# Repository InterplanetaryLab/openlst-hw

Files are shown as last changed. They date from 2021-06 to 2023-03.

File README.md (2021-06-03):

Interplanetary Initiative Lab Fork - OpenLST Reference Hardware
==========================
Due to the Qorvo Power Amplifier in the original design being deprecated, 
the power amplifier was swapped to the newer Qorovo RFFM6406. 
This was more of just a name change as the pinout is identical and the 
electrical specifications of both chips are nearly identical.

*Note - Gerbel files should not need to be updated *

OpenLST Reference Hardware
==========================

This repository contains a KiCad project with a hardware reference
implementation for the OpenLST.  This design is a simplified version
of the Texas Instruments CC1110 432 MHz reference design.  A 1 watt
power amplifier module has been added to increase operating range.
The design is intended for use at 437 MHz, however, it may be modified
for use at other frequencies.

The user is responsible for obtaining and maintaining the necessary
license to operate this radio.  The example project uses frequencies
in the US Amateur Radio UHF band. Transmissions in this band require a
valid FCC license and compliance with CFR Part 97.

board rendering

Contents
--------

This repository contains the following items:

  * [KiCAD 4.0](http://kicad-pcb.org/) project with self-contained part library
  * [Schematic](pdf/openlst-hw.pdf) in PDF form
  * [Bill of materials](bom/) with ordering information for components
  * [Gerber files](gerber/) for PCB fabrication

License & Legal Information
---------------------------

Copyright 2018 Planet Labs Inc. This work is licensed under a
Creative Commons Attribution-ShareAlike 4.0 International License.

This document may contain technology or software the export of which
is or may be restricted by the Export Administration Act and the
Export Administration Regulations (EAR), 15 C.F.R. parts
730-774. Diversion contrary to U.S. law is prohibited.

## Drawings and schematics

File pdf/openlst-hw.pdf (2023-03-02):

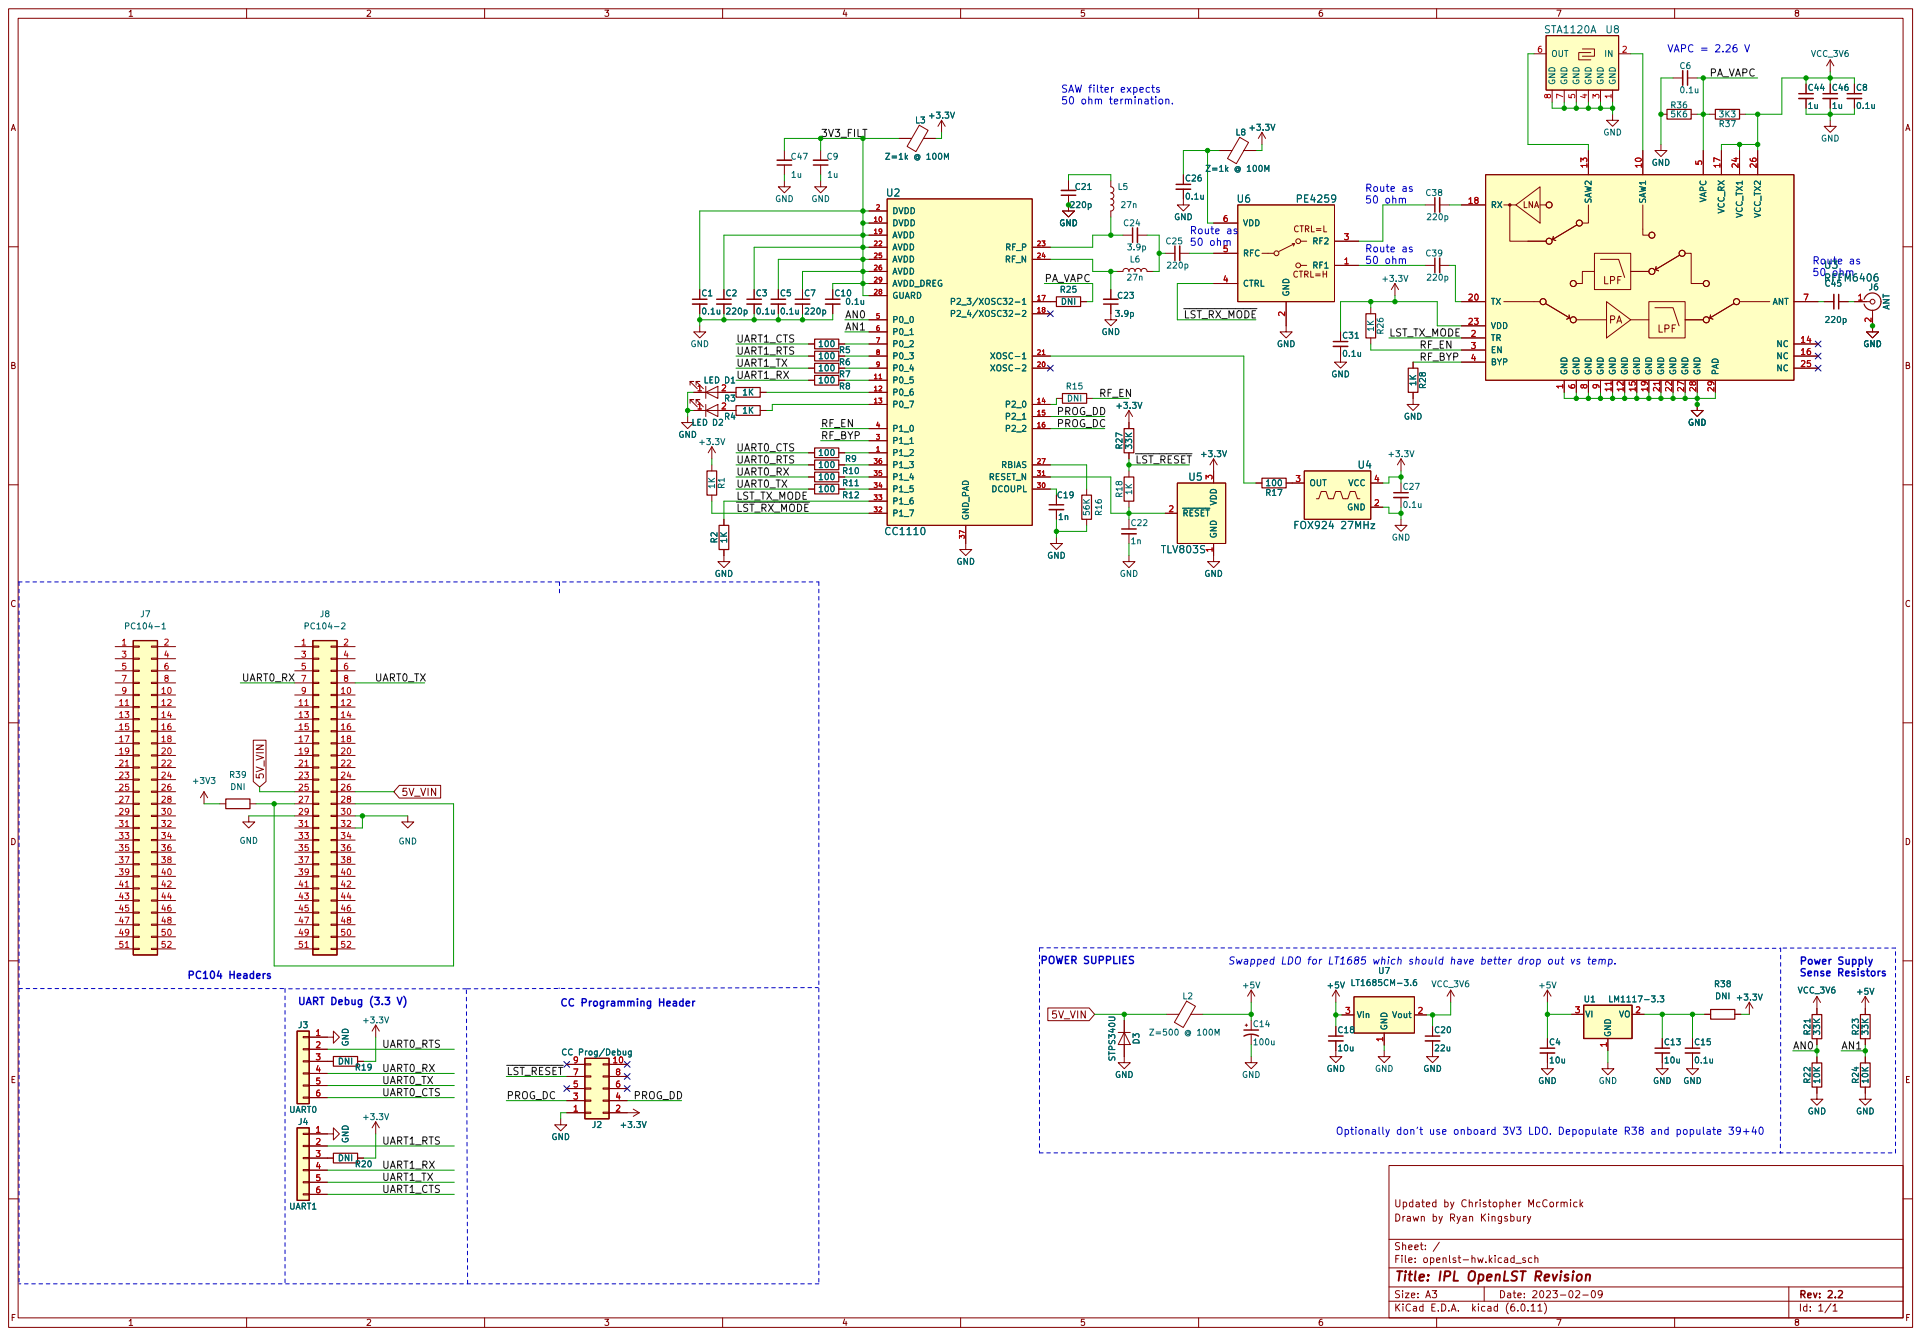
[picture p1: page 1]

SAW filter expects 50 ohm termination.

3 GND U4 FOX924 27MHz GND 2 OUT 3 VCC 4 R17

29 | 30
31 | 32

Swapped LDO for LT1685 which should have better drop out vs temp.

Sense Resistors

1 VO 2 VI 3 U1 LM1117-3.3 GND GND GND GND GND GND

1 VO 2 VI 3 GND GND GND GND

UART0_RX

5 5 | | PROG_DC

UART1_RX

UART1_TX 5 5
6 UART1_CTS

File: openlst-hw.kicad_sch Sheet: / Drawn by Ryan | Kingsbury

Id: 1/1 Title: IPL OpenLST Revision

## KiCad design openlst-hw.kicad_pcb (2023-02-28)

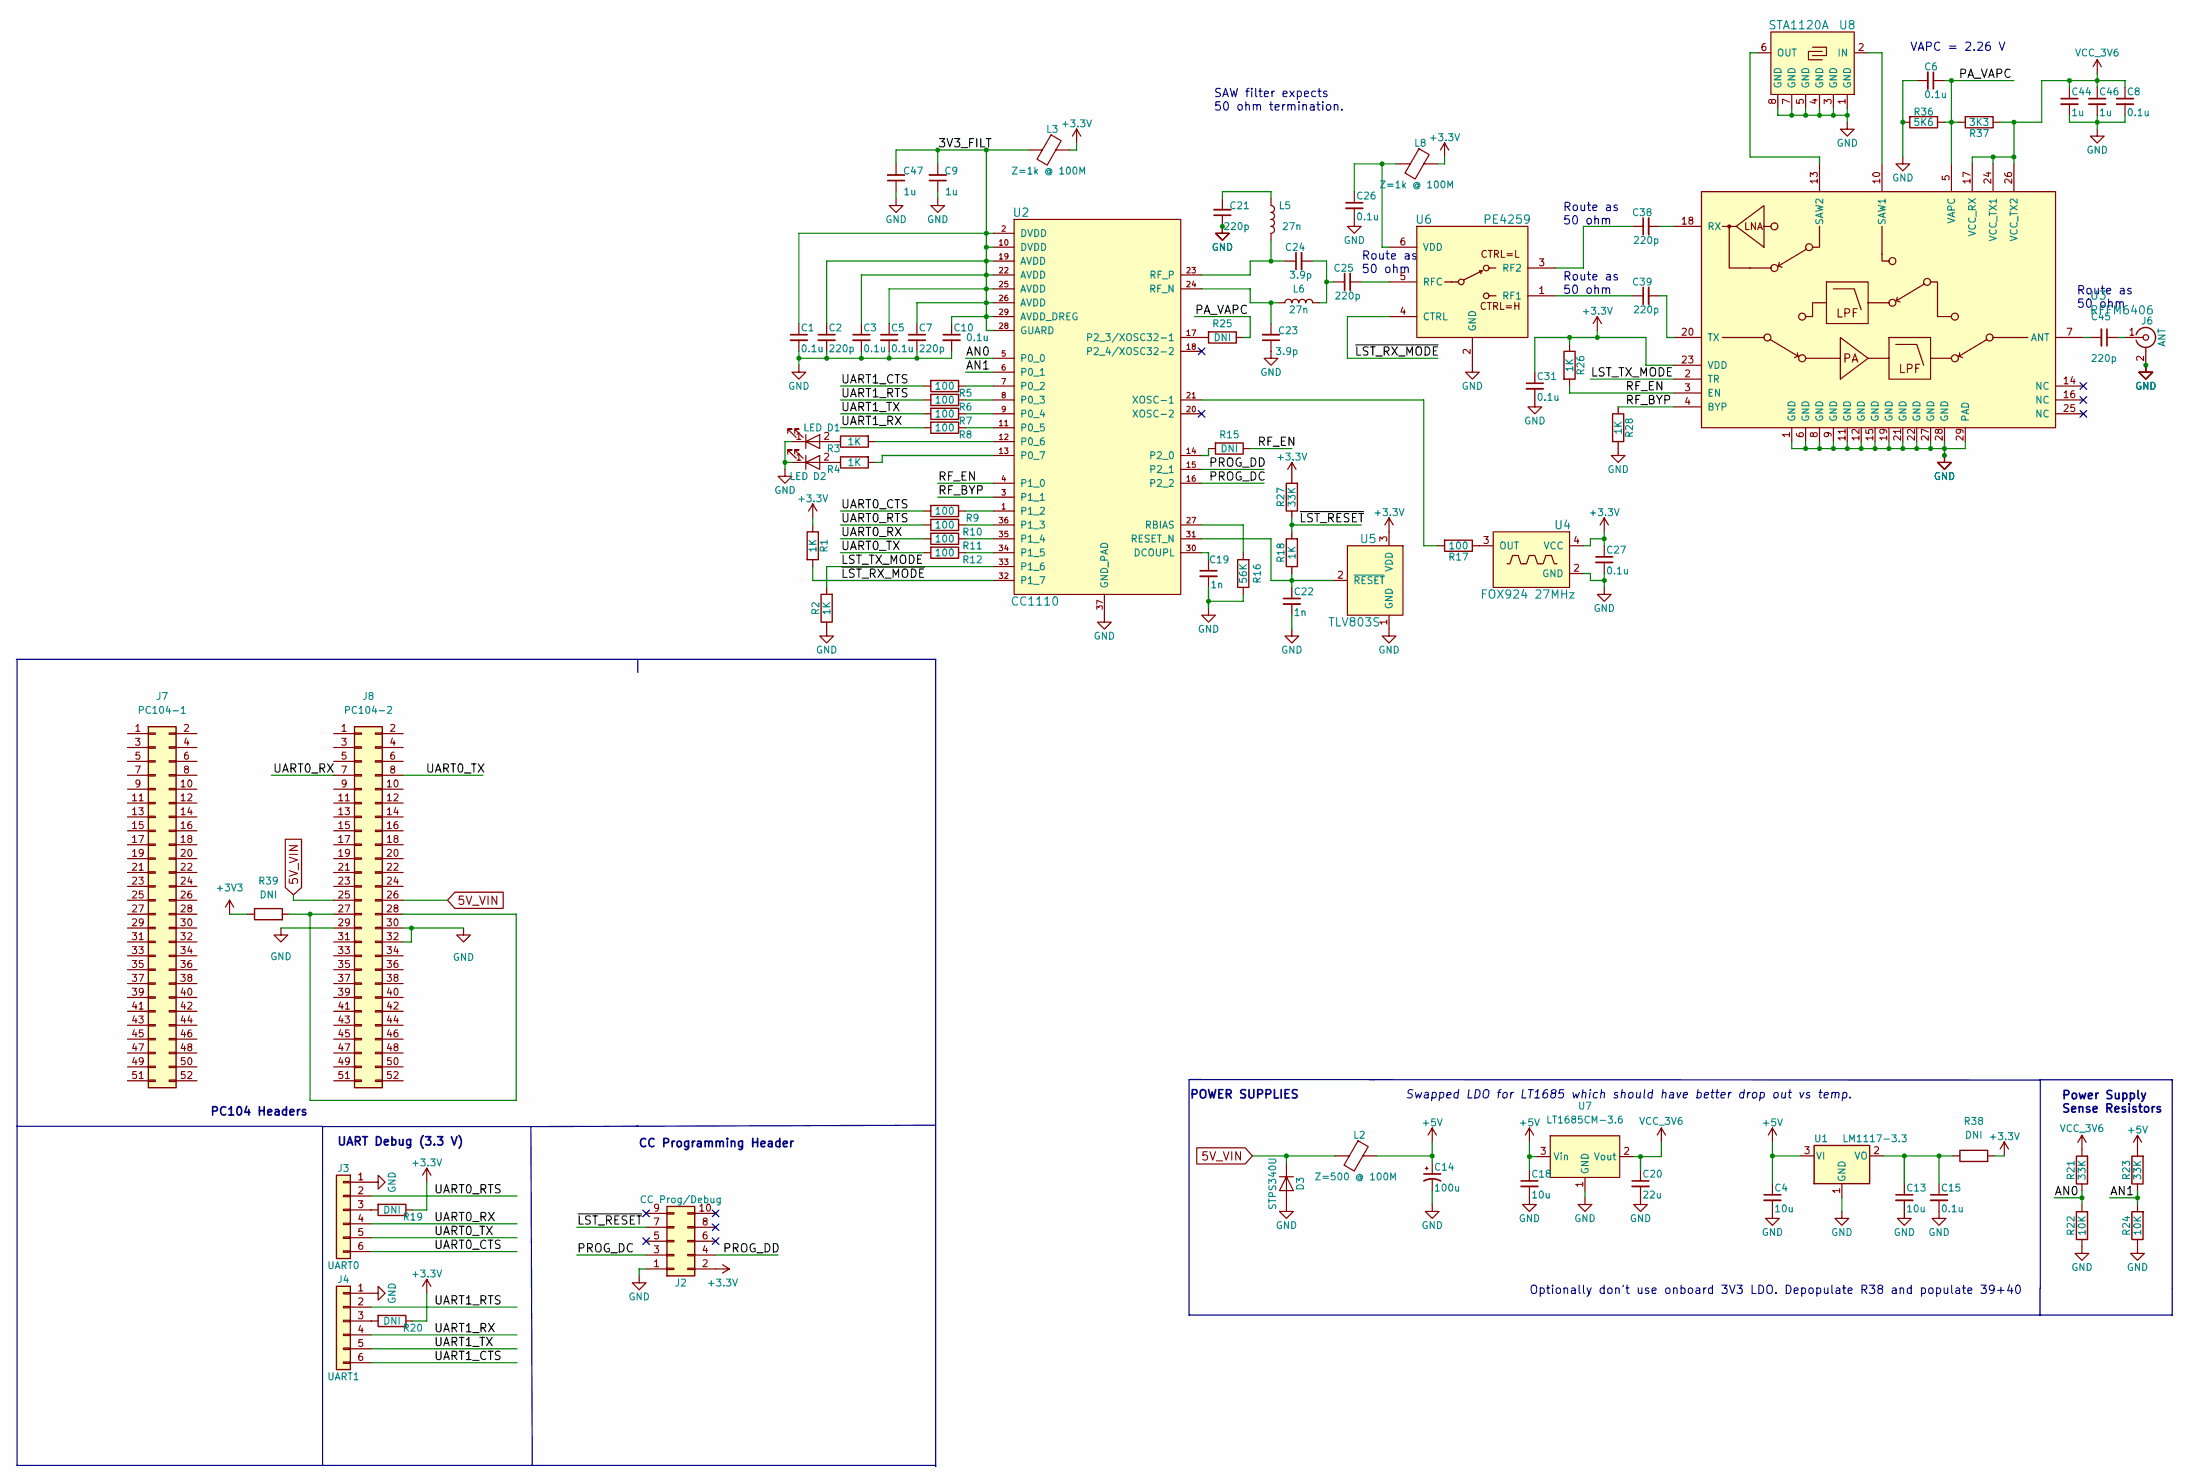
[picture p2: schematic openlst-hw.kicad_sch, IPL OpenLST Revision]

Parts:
C1, C3, C5, C6, C8, C10, C15, C26, C27, C31: 0.1u; C_0603_1608Metric; ManufPN 0603YC104K4T4A
C2, C7, C21, C25, C38, C39, C45: 220p; C_0402_1005Metric; ManufPN C0402C221J2GACAUTO
C4, C13, C18: 10u; C_0603_1608Metric; ManufPN GRT188C81A106ME13D
C9, C44, C46, C47: 1u; C_0603_1608Metric; ManufPN CL10B105MO8NNWC
C14: 100u; CP_EIA-3528-15_AVX-H; ManufPN TPSB107M010R0400
C19, C22: 1n; C_0603_1608Metric; ManufPN GCM188R71E102KA37D
C20: 22u; C_0603_1608Metric; ManufPN GRT188C81A106ME13D
C23, C24: 3.9p; C_0402_1005Metric; ManufPN GJM1555C1H3R9CB01D
D1: LED; LED_0603_1608Metric; ManufPN 150060VS75000
D2: LED; LED_0603_1608Metric; ManufPN 150060SS75000
D3: STPS340U; D_SMB; ManufPN STPS340U
J2: CC Prog/Debug; PinHeader_2x05_P1.27mm_Vertical_SMD; ManufPN FTSH-105-01-L-DV-K-P
J3: UART0; PinHeader_1x06_P2.54mm_Vertical; ManufPN 61300611121
J4: UART1; PinHeader_1x06_P2.54mm_Vertical; ManufPN 61300611121
J6: ANT; SMA_Amphenol_132134_Vertical; ManufPN 732511150
J7: PC104-1; PinSocket_2x26_P2.54mm_Vertical
J8: PC104-2; PinSocket_2x26_P2.54mm_Vertical
L2: Z=500 @ 100M; L_1206_3216Metric; ManufPN MI1206L501R-10
L3, L8: Z=1k @ 100M; L_0603_1608Metric; ManufPN 74279266
L5, L6: 27n; L_0402_1005Metric; ManufPN LQW15AN27NJ00D
R1, R2, R3, R4, R18, R26, R28: 1K; R_0603_1608Metric; ManufPN RC0603JR-071KL
R5, R6, R7, R8, R9, R10, R11, R12, R17: 100; R_0603_1608Metric; ManufPN AC0603FR-07100RL
R15, R19, R20, R25: DNI; R_0603_1608Metric
R16: 56K; R_0603_1608Metric; ManufPN RMCF0603FT56K0
R21, R23, R27: 33K; R_0603_1608Metric; ManufPN AC0603FR-0733KL
R22, R24: 10K; R_0603_1608Metric; ManufPN RC0603JR-0710KL
R36: 5K6; R_0603_1608Metric; ManufPN RMCF0603FT5K60
R37: 3K3; R_0603_1608Metric; ManufPN RMCF0603FT3K30
R38, R39: DNI; R_0603_1608Metric_Pad0.98x0.95mm_HandSolder
U1: LM1117-3.3; SOT-223-3_TabPin2; ManufPN LM1117IMP-3.3/NOPB
U2: CC1110; TI_CC_QFN36; ManufPN CC1110F32RHHR
U3: RFFM6406; Qorvo_LGA_28
U4: FOX924 27MHz; Oscillator_SMD_Fordahl_DFAS15-4Pin_5.0x3.2mm; ManufPN FT5HNBPK27.0-T1
U5: TLV803S; SOT-23; ManufPN TLV803SDBZR
U6: PE4259; SOT-363_SC-70-6; ManufPN 4259-63
U7: LT1685CM-3.6; TO-263-3_TabPin2
U8: STA1120A; SAW-8_3.8mm; ManufPN STA1120A

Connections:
5V_VIN: D3.1 (K), J8.25, J8.26, L2.2
+5V: C4.1, C14.1, C18.1, L2.1, R23.2, U1.3 (VI), U7.3 (Vin)
/3V3_FILT: C1.1, C2.1, C3.1, C5.1, C7.1, C9.2, C10.1, C47.2, L3.2, U2.2 (DVDD), U2.10 (DVDD), U2.19 (AVDD), U2.22 (AVDD), U2.25 (AVDD), U2.26 (AVDD), U2.28 (GUARD), U2.29 (AVDD_DREG)
/AN0: R21.1, R22.2, U2.5 (P0_0)
/AN1: R23.1, R24.2, U2.6 (P0_1)
/LST_TX_MODE: R2.2, U2.33 (P1_6), U3.2 (TR); also elsewhere on the board
/PA_VAPC: C6.1, R25.1, R36.1, R37.2, U3.5 (VAPC)
/PROG_DC: J2.3, U2.16 (P2_2)
/PROG_DD: J2.4, U2.15 (P2_1)
/RF_BYP: R28.1, U2.3 (P1_1), U3.4 (BYP)
/RF_EN: R15.1, R26.2, U2.4 (P1_0), U3.3 (EN)
/UART0_CTS: J3.6, R9.2
/UART0_RTS: J3.2, R10.2
/UART0_RX: J3.4, J8.7, R11.2
/UART0_TX: J3.5, J8.8, R12.2
/UART1_CTS: J4.6, R5.2
/UART1_RTS: J4.2, R6.2
/UART1_RX: J4.4, R8.2
/UART1_TX: J4.5, R7.2
/~LST_RESET: J2.7, R18.2, R27.1
/~LST_RX_MODE: R1.2, U2.32 (P1_7), U6.4 (CTRL); also elsewhere on the board
GND: C1.2, C2.2, C3.2, C4.2, C5.2, C6.2, C7.2, C8.2, C9.1, C10.2, C13.2, C14.2, C15.2, C18.2, C19.2, C20.2, C21.1, C22.2, C23.1, C26.2, C27.2, C31.2, C44.2, C46.2, C47.1, D1.1 (K), D2.1 (K), D3.2 (A), J2.1, J3.1, J4.1, J6.2 (Ext), J8.29, J8.30, J8.32, R2.1, R16.1, R22.1, R24.1, R28.2, R36.2, U1.1 (GND), U2.37 (GND_PAD), U3.1 (GND), U3.6 (GND), U3.8 (GND), U3.9 (GND), U3.11 (GND), U3.12 (GND), U3.15 (GND), U3.19 (GND), U3.21 (GND), U3.22 (GND), U3.27 (GND), U3.28 (GND), U3.29 (PAD), U4.2 (GND), U5.1 (GND), U6.2 (GND), U7.1 (GND), U8.1 (GND), U8.3 (GND), U8.4 (GND), U8.5 (GND), U8.7 (GND), U8.8 (GND); also elsewhere on the board
unnamed: C13.1, C15.1, R38.1, U1.2 (VO)
unnamed: C19.1, U2.30 (DCOUPL)
unnamed: C21.2, L5.1
unnamed: C22.1, R18.1, U2.31 (RESET_N), U5.2 (~RESET)
unnamed: C23.2, L6.1, U2.24 (RF_N)
unnamed: C24.1, L5.2, U2.23 (RF_P)
unnamed: C24.2, C25.1, L6.2
unnamed: C25.2, U6.5 (RFC)
unnamed: C26.1, L8.2, U6.6 (VDD)
unnamed: C38.1, U6.3 (RF2)
unnamed: C38.2, U3.18 (RX)
unnamed: C39.1, U6.1 (RF1)
unnamed: C39.2, U3.20 (TX)
unnamed: C45.1, J6.1 (In)
unnamed: C45.2, U3.7 (ANT)
unnamed: D1.2 (A), R3.1
unnamed: D2.2 (A), R4.1
unnamed: J3.3, R19.2
unnamed: J4.3, R20.2
unnamed: J8.27, J8.28, R39.2
unnamed: R3.2, U2.12 (P0_6)
unnamed: R4.2, U2.13 (P0_7)
unnamed: R5.1, U2.7 (P0_2)
unnamed: R6.1, U2.8 (P0_3)
unnamed: R7.1, U2.9 (P0_4)
unnamed: R8.1, U2.11 (P0_5)
unnamed: R9.1, U2.1 (P1_2)
unnamed: R10.1, U2.36 (P1_3)
unnamed: R11.1, U2.35 (P1_4)
unnamed: R12.1, U2.34 (P1_5)
unnamed: R15.2, U2.14 (P2_0)
unnamed: R16.2, U2.27 (RBIAS)
unnamed: R17.1, U4.3 (OUT)
unnamed: R17.2, U2.21 (XOSC-1)
unnamed: R25.2, U2.17 (P2_3/XOSC32-1)
unnamed: U3.10 (SAW1), U8.2 (IN)
unnamed: U3.13 (SAW2), U8.6 (OUT)
VCC_3V6: C8.1, C20.1, C44.1, C46.1, R21.2, R37.1, U3.17 (VCC_RX), U3.24 (VCC_TX1), U3.26 (VCC_TX2), U7.2 (Vout)

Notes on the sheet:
Power Supply Sense Resistors
Swapped LDO for LT1685 which should have better drop out vs temp.
Route as 50 ohm
VAPC = 2.26 V
PC104 Headers
SAW filter expects 50 ohm termination.
Optionally don't use onboard 3V3 LDO. Depopulate R38 and populate 39+40
POWER SUPPLIES
UART Debug (3.3 V)
CC Programming Header

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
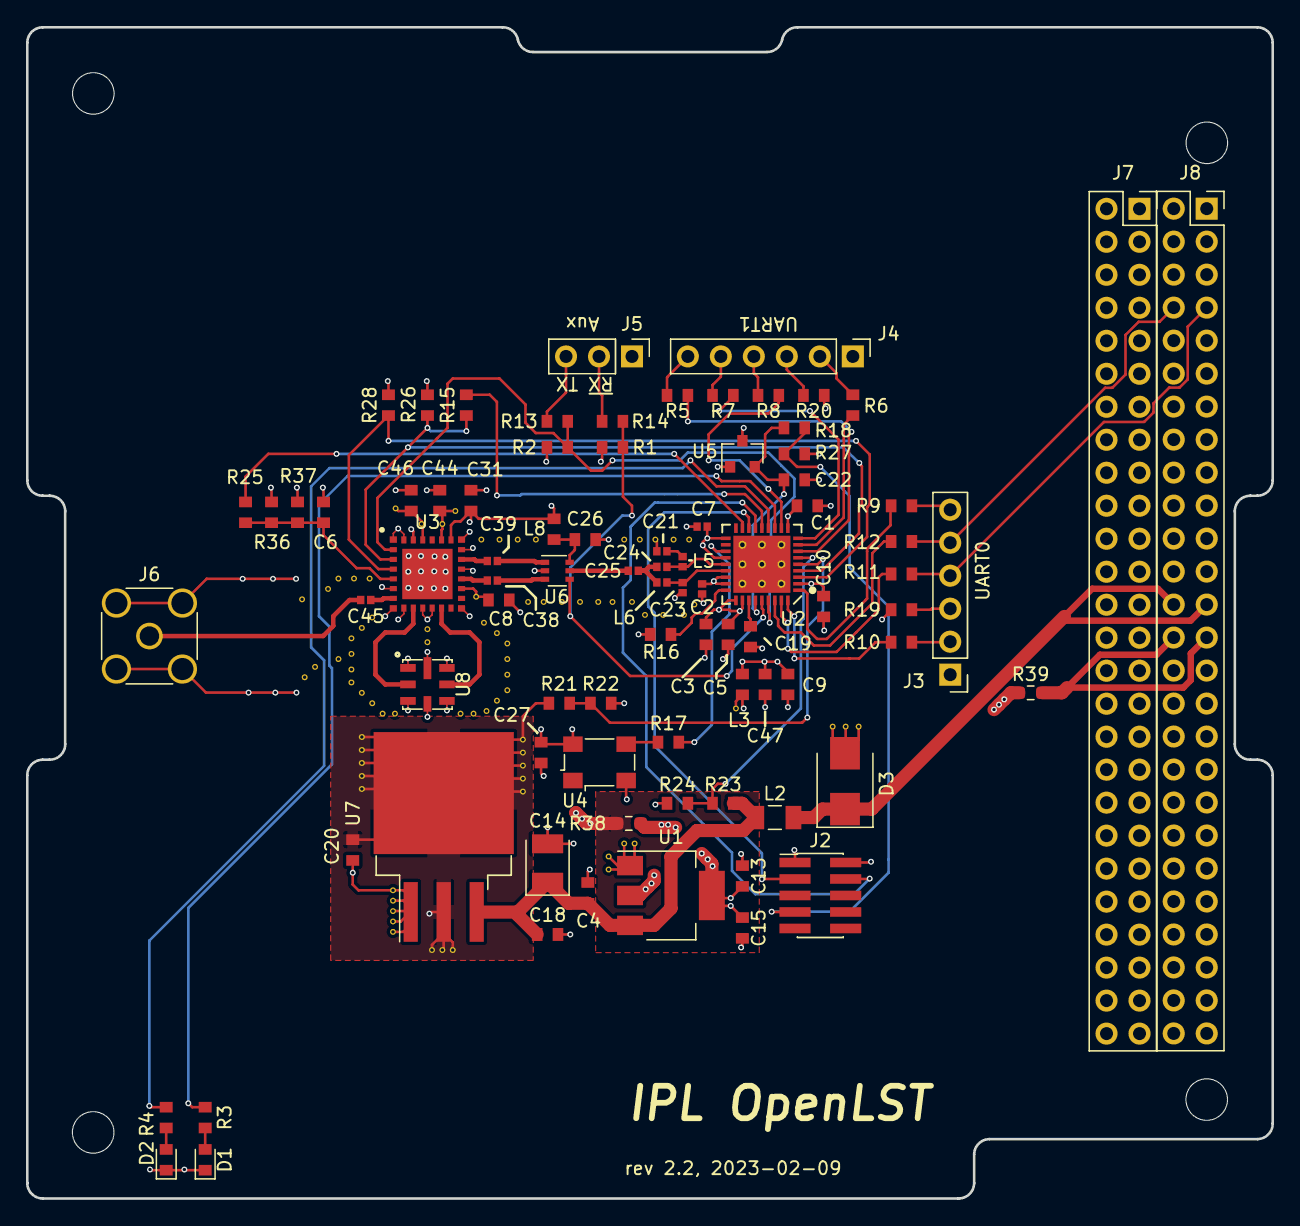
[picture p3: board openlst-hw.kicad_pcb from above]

Board: 4 copper layers, 95.9 x 90.2 mm, 89 parts (0 on the bottom side), 63 nets.

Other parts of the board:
J5: Control Outputs; PinHeader_1x03_P2.54mm_Vertical
R13, R14: 100; R_0603_1608Metric
REF1, REF2, REF3, REF4: MountingHole_3.2mm_M3

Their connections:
/LST_TX_MODE: R13.1; also elsewhere on the board
/~LST_RX_MODE: R14.1; also elsewhere on the board
GND: J5.1; also elsewhere on the board
unnamed: J5.2, R14.2
unnamed: J5.3, R13.2

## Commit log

2021-06-03 updated schematic to use the newer qorvo power amplifier
    [openlst-hw-2021-06-03-12-04-50.sch]
2023-02-09 CAM: commiting v2.2 (inprogress) which makes the openlst board fit in a PC104 stack and swaps an ldo
    [openlst-hw.kicad_pcb, openlst-hw.kicad_sch]
2023-02-16 CAM: commiting current revision
    [openlst-hw.kicad_pcb, openlst-hw.kicad_sch]
2023-02-28 CAM: updated layout to fix some issues with ground plane arrangement
    [openlst-hw.kicad_pcb, openlst-hw.kicad_sch]
2023-03-02 CAM: updated schematic pdf
